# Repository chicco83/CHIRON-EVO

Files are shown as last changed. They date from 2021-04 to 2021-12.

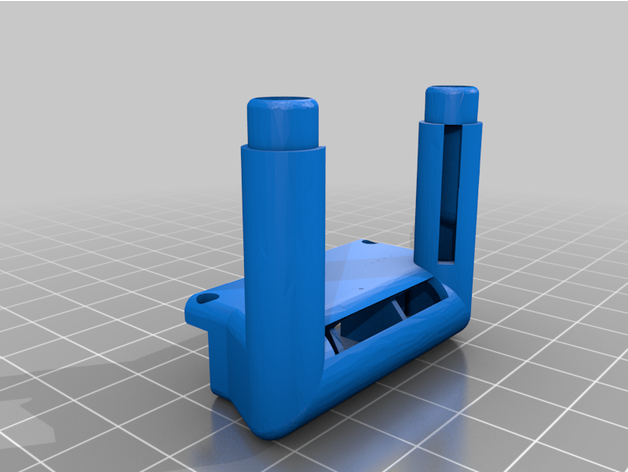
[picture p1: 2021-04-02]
CHIRON/MOD HARDWARE/Chiron+Fan+Duct+Shorter+for+better+print+clearance/images/CHIRON_FAN_DUCT_height_reduce.png

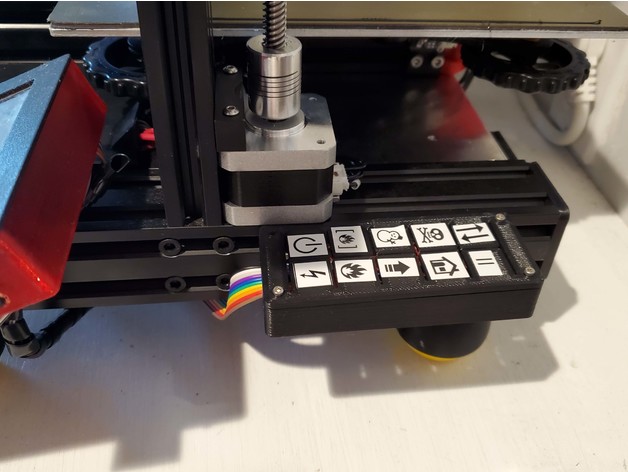
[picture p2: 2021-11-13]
CHIRON/MOD HARDWARE/PANNELLO PULSANTI/Octoprint+Buttonbox+/images/20200816_113341-2.jpg

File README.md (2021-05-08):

# CHIRON-EVO
repository delle modifiche che ho attuato alla mia anycubic chiron

UPDATES PRINTER.CFG

8-5-21 settato  stealthchop_threshold a 999 per assi X e Y e a 1 per Z, Z1 ed E quindi attivo sempre sui primi due assi e sempre disattivo su estrusore e asse Z
8-5-21 aggiunto SCREW ADJUST
8-5-21 aggiunto SuperSlicer_2.3.6a 4-5-21 NIGHTLY

FUNZIONI IMPLEMENTATE IN KLIPPER PRINTER.CFG

[output_pin power]
accensione e spegnimento della stampante tramite semplice rele che interrompe il positivo che esce dal connettore della spina. vedi foto nella sezione MOD HARDWARE / INSTALLAZIONE RELE

[idle_timeout]
se dopo 5 minuti dal riscaldamento la stampante non ha ricevuto input, ritrae il filamento spegne hotend e piatto, suona e da un output su console che avvisa dell'avvenuto idle_timeout

[temperature_sensor Raspberry CPU]  
nelle temperature viene mostrata anche quella della cpu del raspberry

gli stepper sono gia predisposti per lavorare con i driver 4988 o 2209
da calibrare in base alla propria meccanica le rotation_distance
https://github.com/KevinOConnor/klipper/blob/master/docs/Rotation_Distance.md

#[temperature_sensor TMC_2209]
aggiunto un semplice termistore da hotend collegato al pin t2 per monitorare la temperatura dei tmc al momento il codice è disattivato e gira quello nella sezione 

[temperature_fan stepper_driver_fan]
questo codice permette di settare la temperatura obiettivo da mantenere per i driver e la ventola varia in automatico la propria velocita.
per ottenere maggiore silezionsita ho collegato assieme alla ventola della scheda madre anche quella dell'alimentatore.

[endstop_phase]
assieme ai tmc 2209 permette una perfetta calibrazione degli endstop soprattutto sull'asse Z
https://github.com/KevinOConnor/klipper/blob/master/docs/Endstop_Phase.md

[verify_heater extruder]
attivo il controllo delle temperature analogo a marlin in modo da spegnere tutto se le letture delle temperature non sono congrue e quindi c'è un guasto

[verify_heater heater_bed]
come sopra per l'hot bed

[bed_mesh]
attiva la generazione della mesh tramite il sensore di livellamento. se non ne siete in possesso si puo comprare quello per la kossel su aliexpress oppure farlo da soli dato che  è un semplice switch come quello degli endstop meccanici

[pause_resume]
attivata la funzione di messa in pausa e ripresa della stampante

[firmware_retraction]
prevista la ritrazione da firmware ma lasciata disattivata a vantaggio della pressure advance

[gcode_arcs]
inserita la gestione degli archi

[input_shaper]
inserita la sezione per lo smorzamento delle vibrazioni. l'ideale è comprare l'accellerometro che costa pochi spiccioli e farla con quello
https://www.klipper3d.org/Resonance_Compensation.html

[output_pin BEEPER_pin]
abiltiato il beeper per creare macro con avvisi sonori

[filament_switch_sensor my_sensor]
supportato il sensore di fine filamento
in caso di fine filamento la stampante va in pausa ed emette un avviso sonoro.
al rilevamento del nuovo filo lo carica automaticamente:lentamente i primi 2 cm, velocemente i successivi 49 e di nuovo lentamente gli ultimi 6 cm
poi riprende la stampa

[SCREW TILT CALCULATE]
indica come regolare le viti del piatto per una perfetta messa in piano fisica

MACRO.CFG

[gcode_macro M600]
macro m600 per cambio filo

[gcode_macro POWER_OFF_PRINTER]
gcode:
  SET_PIN PIN=power value=0

[gcode_macro POWER_ON_PRINTER]
gcode:
  SET_PIN PIN=power value=1
accensione e spegnimento della stampante tramite rele

MOD HARDWARE PER LA STAMPANTE

hotend trianglelab e3d v6
https://it.aliexpress.com/item/32844313509.html?spm=a2g0s.9042311.0.0.27424c4dBxZaBv
una volta montato andranno alzati gli endstop ottici o stampate alette piu lunghe altrimenti non arriva a fare il trigger del fine corsa

estrusore trianglelab  bmg v2
https://it.aliexpress.com/item/32917029058.html?spm=a2g0s.9042311.0.0.27424c4dk6avcs

barre filettate di rinforzo M10 con pezzi stampati per sfruttare la totale altezza della stampante qui
il progetto non è mio e dalla struttura delle cartelle sembra derivare da thingverse su cui però non l'ho trovato quindi non so a chi dare i credit

driver tmc 2209 5 pz versione UART
https://it.aliexpress.com/item/33029587820.html?spm=a2g0s.9042311.0.0.27424c4dK0OpVI
SEGUE GUIDA DEDICATA

tastatore per autobed leveling
https://it.aliexpress.com/item/4000792963251.html?spm=a2g0s.9042311.0.0.27424c4dK0OpVI
io ho preso la stampante usata e non c'era
SEGUE GUIDA DEDICACATA

accellerometro per ottimizzazione delle vibrazioni
https://it.aliexpress.com/item/32922294688.html?spm=a2g0s.9042311.0.0.27424c4dk6avcs

aggiunta rele per spegnimento stampante da klipper.
va installato un rele sul filo rosso saldato al connettore della spina e spostato il jumper che imposta l'alimentazione della trigorilla nella posizione usb in modo che la scheda sia alimentata dal raspberry. vedi foto nella cartella MOD HARDWARE / INSTALLAZIONE RELE

ELEMENTI DA STAMPARE LEGATI A KLIPPER

ho creato una cartella dedicata sotto klipper. al momento contiene un case per il rasp e un supporto un tablet da 7 pollici da usare come interfaccia localae

SOFTWARE

win32imager per fare un clone di backup della sd
https://sourceforge.net/projects/win32diskimager/

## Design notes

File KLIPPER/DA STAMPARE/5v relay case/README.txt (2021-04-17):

Customizable 5V relay case (updated version) by Zerkin on Thingiverse: https://www.thingiverse.com/thing:3851101

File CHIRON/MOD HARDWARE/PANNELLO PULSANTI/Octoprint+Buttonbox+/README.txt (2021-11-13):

Octoprint Buttonbox  by eugland on Thingiverse: https://www.thingiverse.com/thing:4571839

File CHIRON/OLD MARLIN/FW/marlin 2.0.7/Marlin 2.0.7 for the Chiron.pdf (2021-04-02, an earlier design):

Marlin 2 for the Chiron by Nick Wells

1 | P a g e

# Marlin 2.0.7 for the Chiron

## Introduction

I do not work for Anycubic and have no affiliation with Anycubic Ltd.
I have created this custom version of Marlin to support the factory build of the Anycubic Chiron, as I am a Chiron owner and a long-term user of Marlin firmware.
You are installing this firmware because you want to try new features in Marlin and you know how to safely operate your machine.

This firmware has been tested on the standard factory build Chiron and the printer operates as expected. This is open source firmware that comes with no support, warranty or guarantees. You have chosen to install it and by doing so accept responsibility for any problems, failures and losses that may occur.
If you aren’t sure about upgrading firmware, then please don’t.

The upgrade process is very simple and you can return to the Anycubic standard firmware at any time using the file in this package, or by downloading it from the Anycubic website.

## Firmware Features

Here is a summary of the features enabled in the firmware

All Chiron hardware and front panel features are supported.

### Bed Levelling

- Mesh bed Levelling
- Sensor Bed Probing
- Manual level adjustment
- Enhanced single point adjustment
- Automatic mesh loading after homing

### Preset Calibration

- Stock Hotend PID tune profile
- Stock Heatbed PID tune profile
- Stock extruder E-Step Calibration

### Error Recovery

- Filament out detection and recovery enabled
- Power loss detection and recovery enabled (SD Printing only)
- Auto park head on Pause
- Validated temperature error detection (reduces spurious temperature warnings)

### Printing Features

- Marlin Linear Advance enabled (preset K=8.0)
- Marlin Junction Deviation (preset to 0.028)
- Live Z axis baby stepping movement from panel during print

### Folder Navigation

The SD card can be navigated like a normal PC folder.
Click a folder name to enter a folder and click .. to go back up to the previous folder.

## Which Version Chiron do I have?

There are newer factory builds of the Chiron with an updated TFT panel that works slightly differently.

## THIS FIRMWARE DOES NOT SUPPORT THE NEW TFT PANEL (yet!)

Original version supported ✓ | New version Not Supported ✗
Use Anycubic firmware v1.3.0 | Use Anycubic Firmware v1.3.5

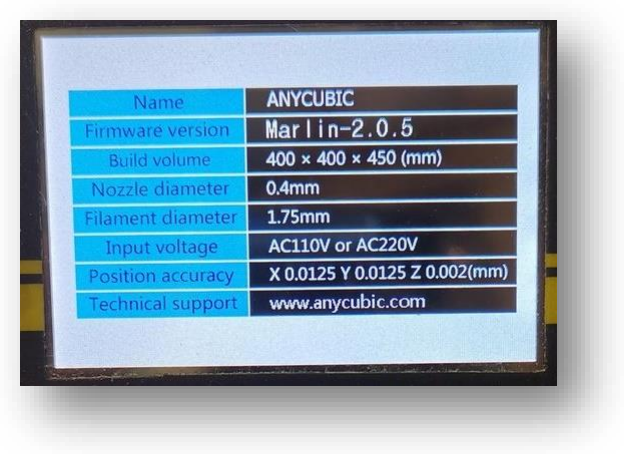
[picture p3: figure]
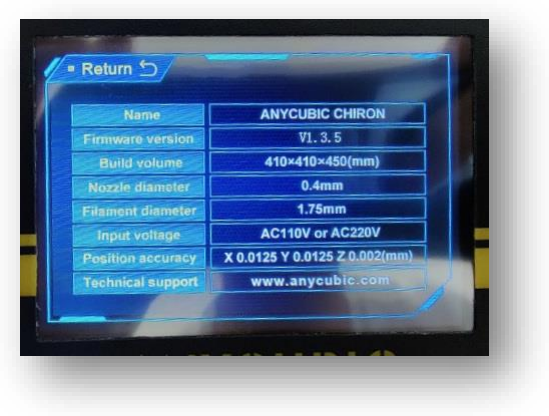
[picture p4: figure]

If you have installed the v2.07 by mistake you can reinstall the original Anycubic firmware in the pack.

## What’s in the package?

### The new Marlin Firmware

This is the version 2.0.7 release of Marlin customised for the Chiron and some command files to send to the printer. The printer will beep after running a command file.

File list

- CHIRON_2.0.7.hex
- Reset EEPROM.gcode
- PID Tune Hotend.gcode
- PID Tune Bed.gcode

### The standard Anycubic Firmware release

This is the standard Anycubic firmware. You can go back and install this version at any time by following the firmware quick start instructions on the next page.

For the old style TFT panel
File list
- CHIRON_1.3.0.hex
- Auto_Leveling.gcode
- Manual_Leveling.code

For the new style TFT panel
File list
- CHIRON_1.3.5.hex
- Auto_Leveling.gcode
- Manual_Leveling.code

There is also a copy of a free terminal program called Termite that may be useful!

## Firmware Installation Quick Start

Please follow these quick instructions to upgrade the printer and get printing. These instructions work with any version of firmware.

### Before You Start (Optional)

If you have already PID tuned and E-Step calibrated your printer it may be worth making a record of your settings. To do this connect a terminal program to the printer and send M503 to display settings. Save this info somewhere useful!

## Things you MUST DO or the printer won’t work correctly

### Upload the firmware

1) Connect your printer to a PC and launch Cura
2) In Cura got to Settings>Printer>Manage Printers…
3) Click Update Firmware then Upload Custom Firmware
4) Browse to the firmware file you want to install and click ok.
5) Once the firmware has installed the printer will reboot
6) You can check the version on the panel under Tools>More>Info

### Reset the printer settings

Every time you change a firmware version you must to reset the controller EEPROM.

Either send the commands M502 M500 from your PC

Or copy Reset EEPROM.gcode onto an SD card and print it.

### Level the bed

Follow the instructions on the next page to level the print bed.

### Things you SHOULD do for optimal printing

The settings in this firmware are specifically calibrated for the Chiron, but if you wish to re run the calibration here’s an easy way to do it!

PID tune the hotend
1) Copy the file PID Tune Hotend.gcode to the SD card and print it.
2) The printer will beep when finished.

PID tune the heated bed
1) Copy the file PID Tune Bed.gcode to the SD card and print it.
2) The printer will beep when finished.

Calibrate the extruder E-STEPS
Please read the included guide ‘Anycubic Chiron Step by Step Extruder flow calibration.pdf’

## How do things work?

### Bed Levelling

The bed levelling uses the Anycubic Probe which creates a 5 x 5 mesh that is used to adjust the Z axis position during print. The mesh is automatically saved after homing and is automatically loaded and applied every time the printer is homed.

Top Tip! The bed levelling will be more accurate if you probe the bed when it is hot!

### Here are the bed levelling steps: Please follow these steps carefully!

1) Home the printer
2) From the panel select Tools>More>Level>Probe make sure the probe is fitted then click OK. The printer will now probe the bed.
3) Once probing has finished, the head will park and you should remove the probe.
4) Now you must set the probe offset. Select Tools>More>Level>Advanced Setting
5) Tap red dot number 13 twice and the head will move to the centre of the bed and will be about 2mm above the bed.
6) Check the ‘ALL’ box and place a piece of paper under the head.
7) Use the +/- buttons to lower the head so that is grips the paper. You should be able to pull the paper but not push it. Now click OK.
8) The bed is now levelled!

### Mesh Point Adjustment

If you want to check and adjust individual points:
1) Home the printer
2) Go to the advanced level menu and click any of the red dots twice.
The head will move to the probe point and you can adjust the level using the +/- buttons on the panel.

NOTE: When using the Advanced Setting screen
- Click OK to save your changes
- Click back to cancel and revert to the last saved values.

### Filament Runout

When the filament runs out, the printer will beep and the head will park. The old filament will be ejected and the printer will beep then you load the new filament and the print will continue.
The extruder heater will shut down after 3 minutes, and will reheat before attempting to feed in the filament or restart the print. Use the ‘Continue’ button on the front panel to tell the printer to continue the process.

The filament workflow looks like this:
1) The filament runs out
2) The printer beeps and parks the head and shows a warning on the panel
3) Printer ejects the remaining filament then beeps 5 times and waits
4) Insert the new filament and click continue
5) The printer will slowly feed 50mm of filament
6) It will then accelerate and feed a further 500mm
7) Finally, it will slow down and purge the last 100mm
8) Once the filament starts to come out of the nozzle, click continue and the print will resume.

### Power loss Recovery

The printer can automatically recover a failed print during a power loss under the following conditions:

### 1. You must be printing from the SD card 2. The print file must be in the root folder 3. You must leave the front 10cm of the bed clear

Note: It is best to have just 1 or 2 files on the SD card for power loss recovery. If you have lots of files on the SD card, the power loss recovery may fail to save the last state when the power goes out. If this happens the job will not auto recover.

The power loss recovery works like this:
1) The power goes out!
2) The printer saves the current printer state into a file called PLR on the root of the SD card.
3) Manually move the print head off the print as it my get stuck.
4) Turn on the printer, you will hear an SOS beep to tell you the printer is in recovery mode.
5) Browse the SD card and select the file that was printing, then click ‘resume’.
6) The printer will home X and Y then will home Z so it should be clear of the print.
7) The bed and hotend will be reheated.
8) The head will then raise to a height 5mm above the point where the print failed.
9) The head will lower onto the print and it will resume where it left off.
10) The PLR file will be automatically deleted.

If the power fails again, the print will be recovered from the new fail point.

If you wish to cancel recovery mode:
1) resume the print then stop it
2) Print a different file
3) Delete the PLR file from the SD card.

### Live Baby Stepping during print

If you need to nudge the Z axis during a print you can now do this from the Advanced levelling menu.

Baby stepping works like this:
1) During a print Select Tools>More>Level>Advanced Setting
2) Make sure ALL is selected, the display will show 0.00
3) Each press of the +/- button will move the head by 0.05 mm
4) If you return to the menu during the print, that value will show how far the Z axis has been nudged.

At the end of the print the nudge value will be cleared. This is a temporary value that is not saved.

WARNING: This feature does not obey end stops so you can push the head into the bed with repeated movements, so use with caution!

### Source Code

The source code for this release is part of the main Marlin Github repository which you can find here:

https://github.com/MarlinFirmware/Marlin

The configuration files for the Chiron are located in the Marlin config repository here:

https://github.com/MarlinFirmware/Configurations

To build your own version of this firmware:

1) Download the Main Marlin Repository
2) Download the Marlin Configurations Repository
3) Replace configuration.h and configuration_adv.h in the Marlin\ folder with the versions in Configurations/config/examples/AnyCubic/Chiron/ in
the Configurations repository.
4) Build away!

### A quick shout out!

Thank you to:
Shane Dekart, Robert Filippo, Bob Modrow, Quentin McCain, Luca Marongiu, Marcin Nowak, JF Kerekes

For risking your machines testing the beta version of the firmware to help get it all working as it should!

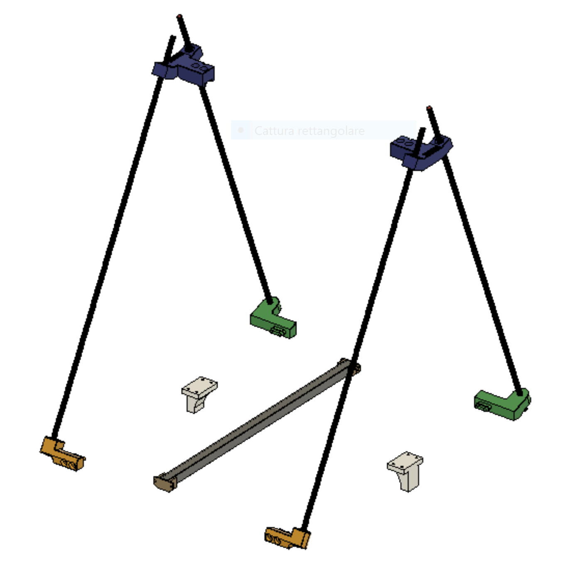
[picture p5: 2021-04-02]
CHIRON/MOD HARDWARE/Supporto Stabilizzante Chiron/Images/Anteprima Upgrade Chiron.PNG

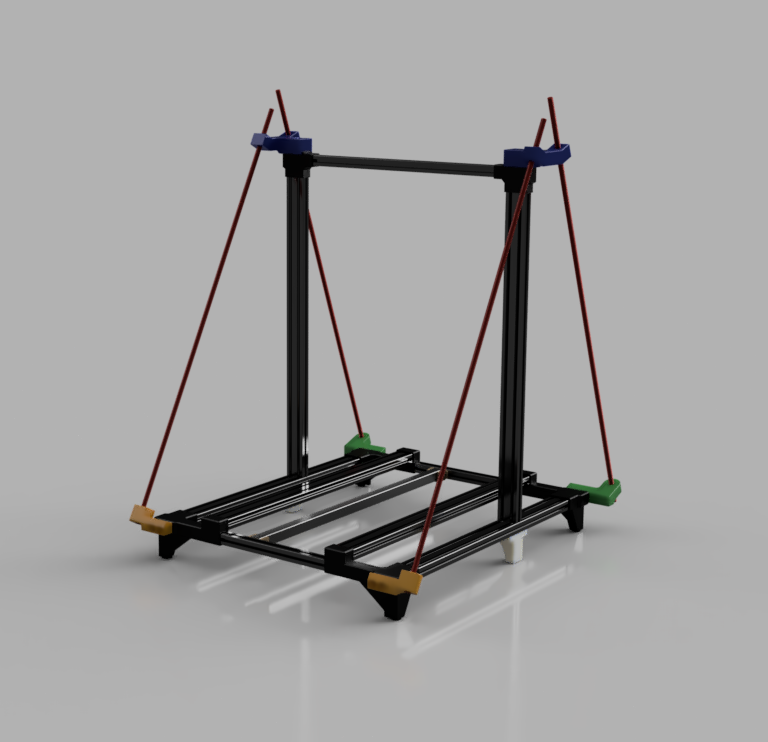
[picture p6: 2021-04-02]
CHIRON/MOD HARDWARE/Supporto Stabilizzante Chiron/Images/Rendering.PNG

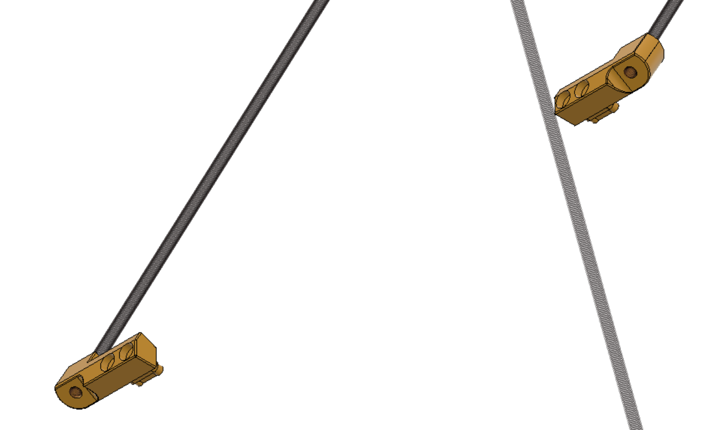
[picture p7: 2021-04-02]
CHIRON/MOD HARDWARE/Supporto Stabilizzante Chiron/Images/Supporto Anteriore Chiron.PNG

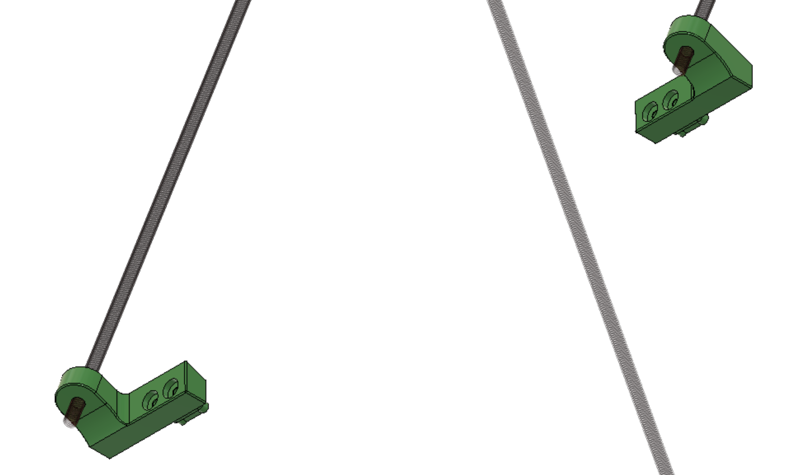
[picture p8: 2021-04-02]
CHIRON/MOD HARDWARE/Supporto Stabilizzante Chiron/Images/Supporto posteriore Chiron.PNG

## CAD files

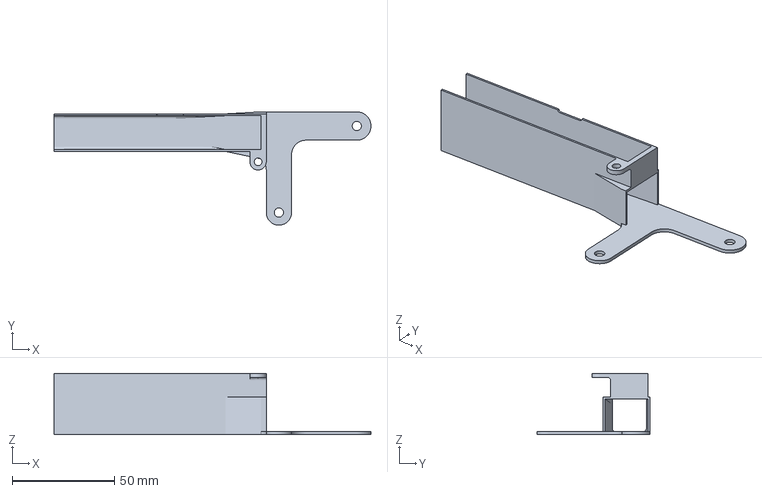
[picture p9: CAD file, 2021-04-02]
CHIRON/MOD HARDWARE/Anycubic_Trigorilla_stepper_driver_cooling_tunnel/files/Trigorilla_stepper_driver_cooling_duct_v2.3mf
154.7 x 55.3 x 30.0 mm

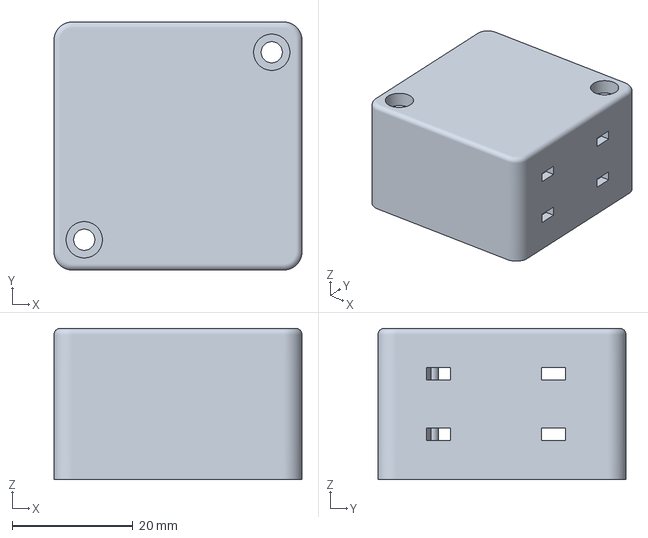
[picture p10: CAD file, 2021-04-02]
CHIRON/MOD HARDWARE/Chiron_X_stepper_cover_with_cable_guide/files/Fusion360_Chiron_cover.3mf
41.0 x 41.0 x 25.0 mm

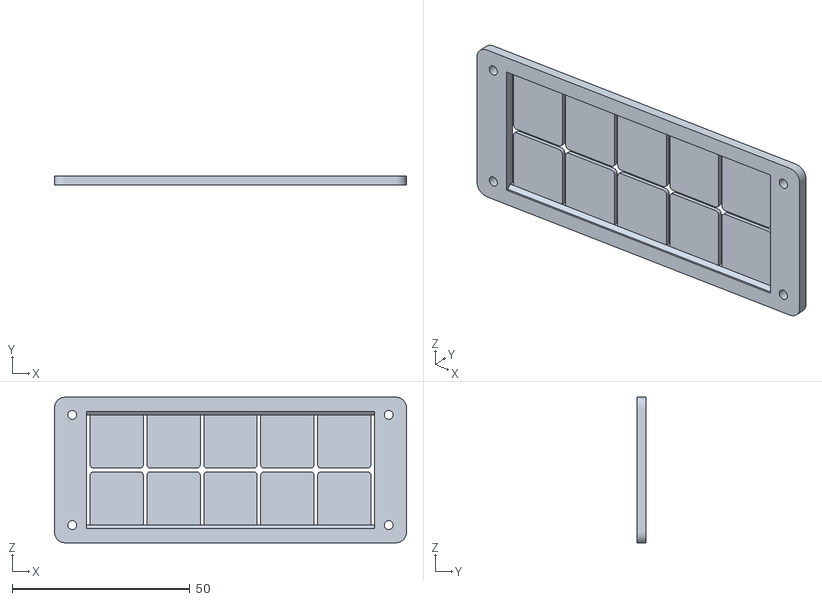
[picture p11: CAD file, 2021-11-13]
CHIRON/MOD HARDWARE/PANNELLO PULSANTI/Octoprint+Buttonbox+/files/buttonpad.stl
99.0 x 2.50 x 41.0

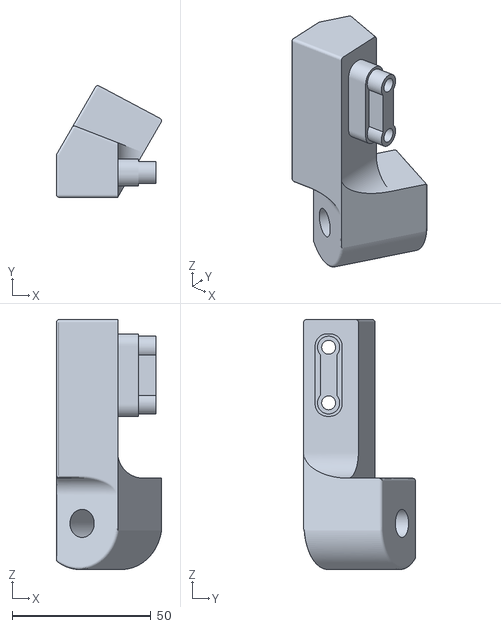
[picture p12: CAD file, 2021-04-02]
CHIRON/MOD HARDWARE/Supporto Stabilizzante Chiron/Files/fatti/Supporto anteriore barra M10 sx Chiron.stl
37.8 x 40.2 x 90.0

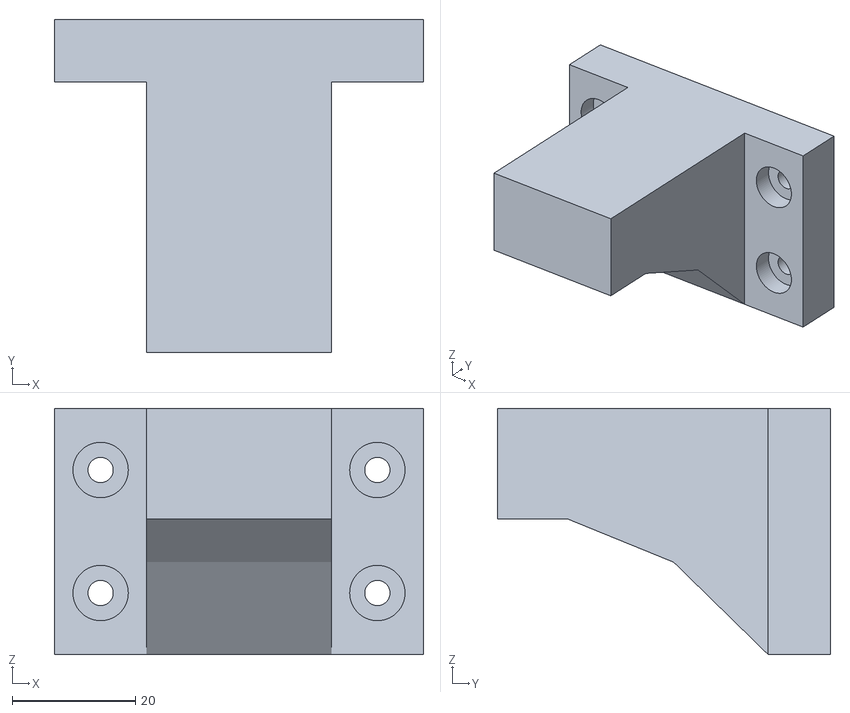
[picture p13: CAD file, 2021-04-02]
CHIRON/MOD HARDWARE/Supporto Stabilizzante Chiron/Files/Piede dx Z Chiron.stl
60.0 x 54.2 x 40.0

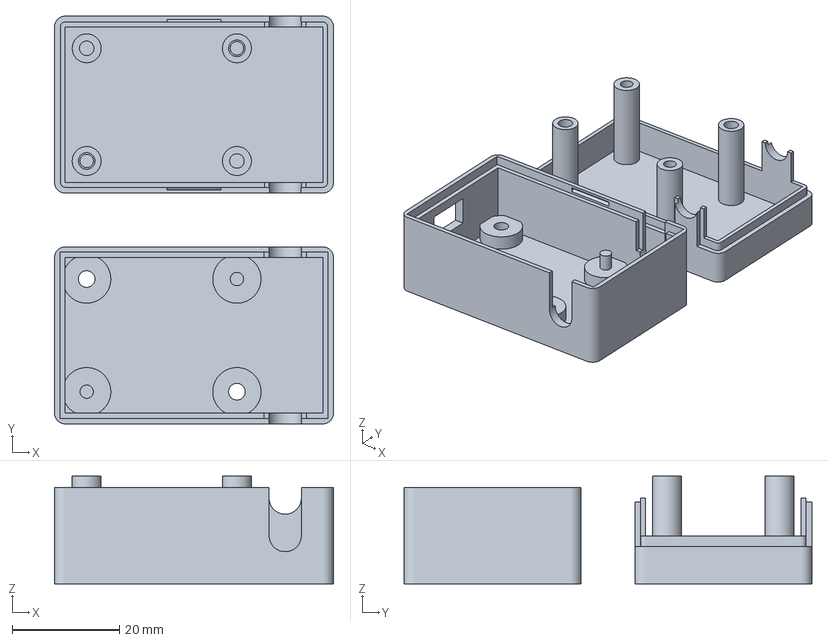
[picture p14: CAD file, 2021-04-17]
KLIPPER/DA STAMPARE/5v relay case/files/relay_case.3mf
52.0 x 76.0 x 20.1 mm

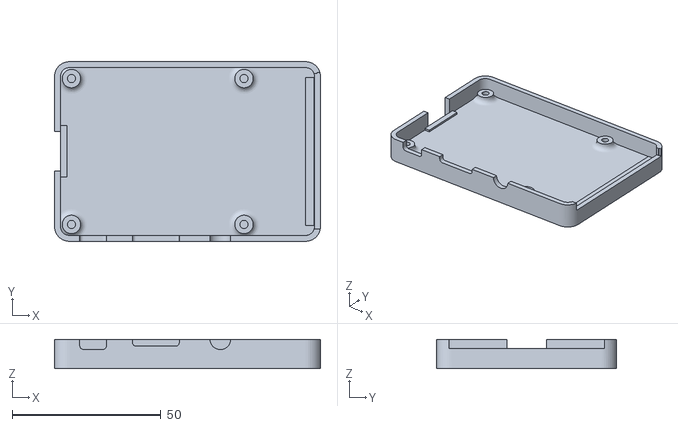
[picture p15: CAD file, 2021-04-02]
KLIPPER/DA STAMPARE/Raspberry_Pi_3_B_Case/files/Pi3_Bottom_Plain.stl
89.4 x 60.4 x 9.75

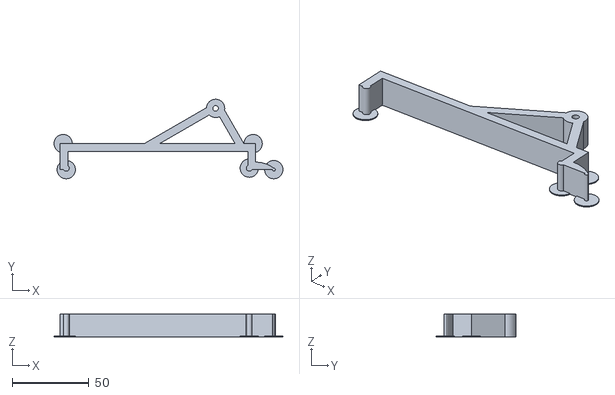
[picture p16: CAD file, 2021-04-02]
KLIPPER/DA STAMPARE/supporto tab 7/clip.stl
149.5 x 52.0 x 15.0

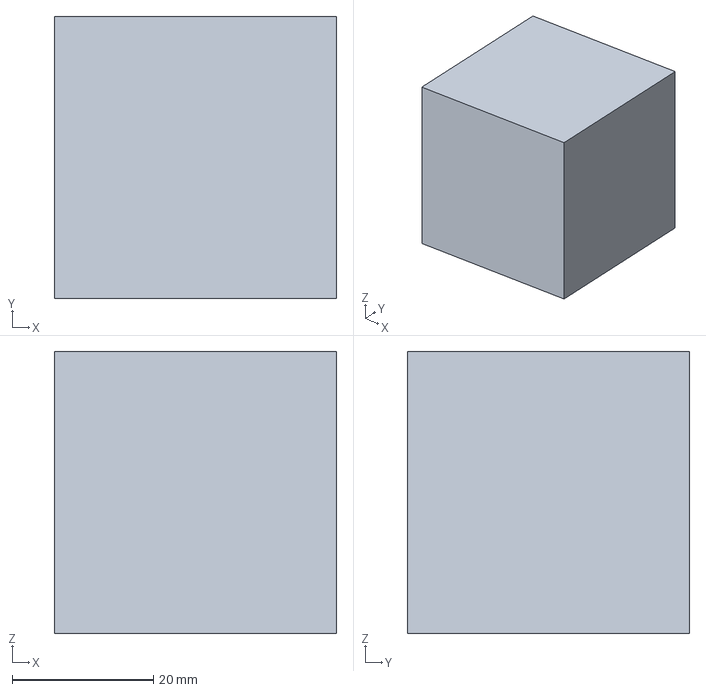
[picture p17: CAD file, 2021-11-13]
TARATURE/cubo flow test.3mf
40.0 x 40.0 x 40.0 mm

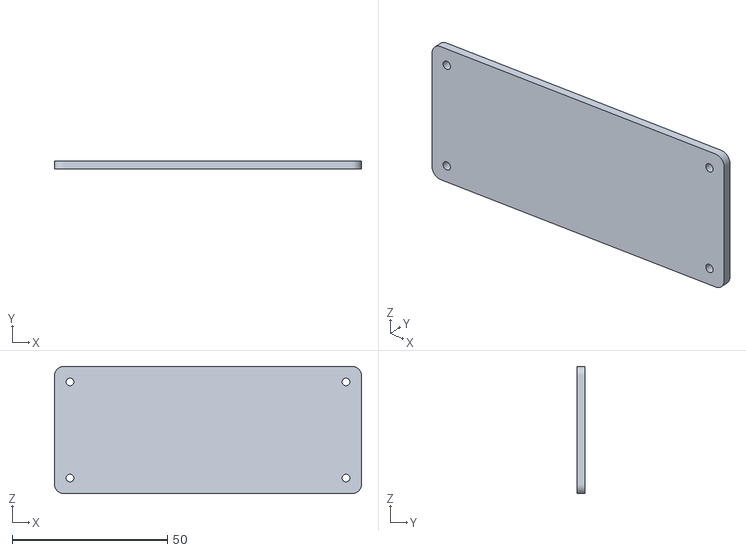
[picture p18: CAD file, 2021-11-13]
CHIRON/MOD HARDWARE/PANNELLO PULSANTI/Octoprint+Buttonbox+/files/tappo inferiore.stl
99.0 x 2.50 x 41.0

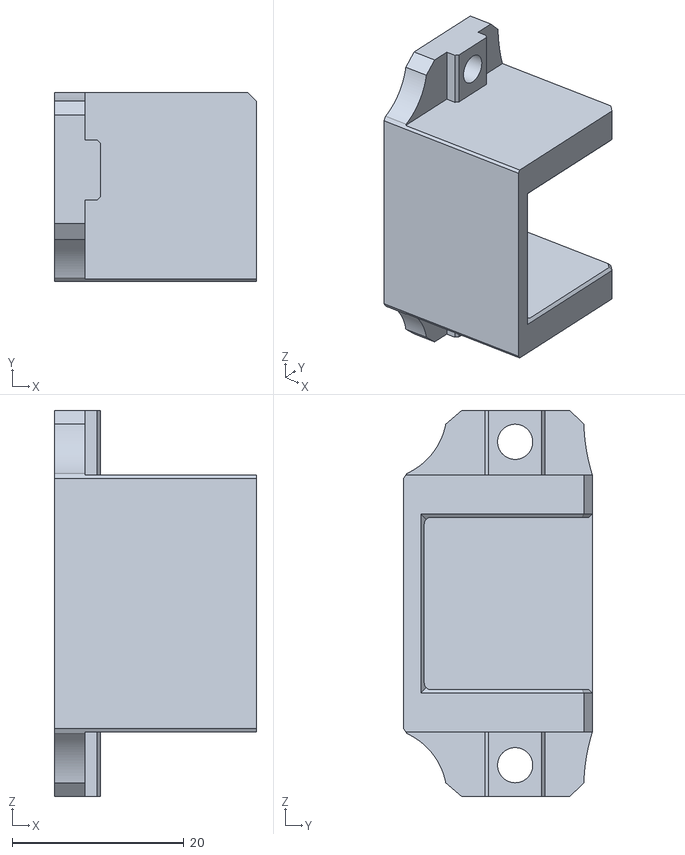
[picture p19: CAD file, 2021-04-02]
CHIRON/MOD HARDWARE/Supporto Stabilizzante Chiron/Files/fatti/Rinforzo asse y scatolato 2020 anteriore Chiron.stl
23.6 x 22.0 x 45.0

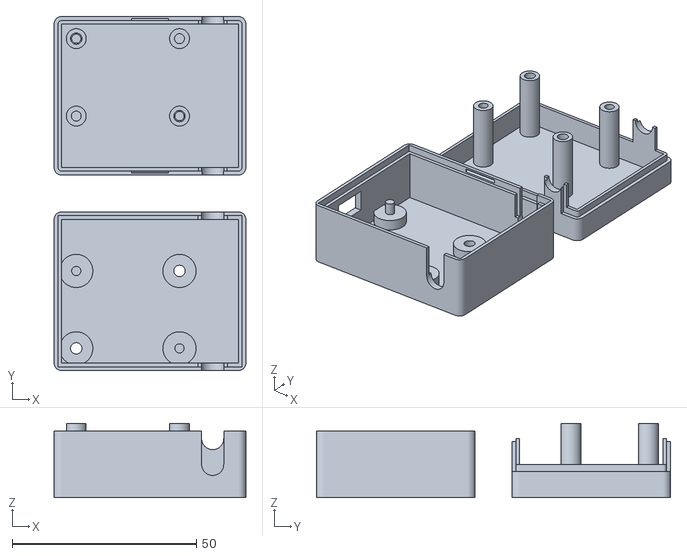
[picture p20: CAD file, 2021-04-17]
KLIPPER/DA STAMPARE/5v relay case/files/relay_case_wide.stl
52.0 x 96.0 x 20.1

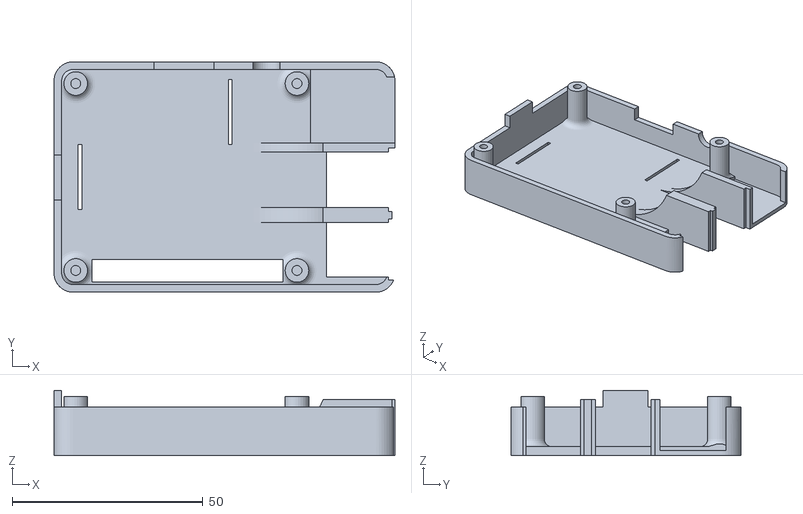
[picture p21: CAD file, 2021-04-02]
KLIPPER/DA STAMPARE/Raspberry_Pi_3_B_Case/files/Pi3_Top_GPIO.stl
89.4 x 60.4 x 17.1

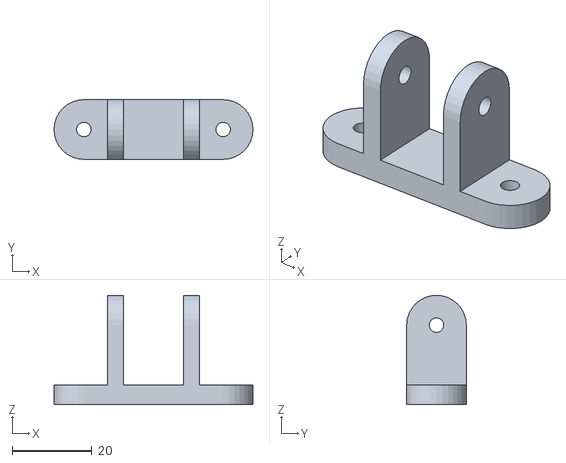
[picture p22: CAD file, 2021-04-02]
KLIPPER/DA STAMPARE/supporto tab 7/mount.stl
50.0 x 15.0 x 27.5

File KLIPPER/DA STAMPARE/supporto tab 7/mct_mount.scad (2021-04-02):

// This script creates a mount for the MatterControl Touch
// tablet for attaching to a 3D printer. 
// 
// I wanted to create this mount so that I can mount my
// MatterControl Touch to the printer in place of the LCD panel.
// If you haven't used one of these before, you will be 
// amazed at its power, ease of use, and convenience. Simply
// stated, the MatterControl Touch is the LCD panel you've 
// always wanted but have never found. There have been some 
// other good attempts at a full featured LCD/computer mount
// but this one is the best hands down. Don't take my word(s)
// for it - try one yourself.
//
// As you can see, you can modify this script to change the
// mount if you want a different type - clamp or whatever.
// You can also change the length of the arm if you want the 
// table to be further away from the print bed. Feel free
// to customize at will!
// 
// Vitamins:
//
// (2) M3 nylock nuts
// (2) M3 nuts
// (2) 15x30mm strips of self adhesive foam ~1/8" thick
// (4) M3 washers
// (1) M3x25mm bolt
// (1) M3x50mm bolt
// (2) M3x8mm bolts
// (1) MatterControl Touch ;)
//
// Note: you may be able to substitute #6 bolts for the longer M3,
//       but you may need to drill out the holes a bit. Or, better,
//       modify the code to use larger holes.
// 
// Instructions:
//
// 1. Print (1) arm, (1) mount, and (2) clips. PLA is fine.
//    I would use 0.3 layer height and 40% infill for strength.
//    No supports are needed. There are pads on the clip at key locations 
//    to help prevent lifting. Just cut those away when printed.
// 2. Attach the mount to the printer using (2) M3x8 bolts and (2) M3 nuts.
// 3. Attach the arm to the mount using (1) M3x25 bolt, (2) M3 washers and 
//    (1) M3 nylock. Do not tighten, just snug the bolt.
// 4. Attach the clips to either side of the arm using (1) M3x50 bolt,
//    (2) M3 washers, and (1) M3 nylock. Do not tighten, just snug the bolt.
// 5. Attach foam strips.
// 6. Clip the MatterControl Touch into the clip, position, and tighten
//    the bolts. 
//    Tip: Use the camera preview to sight your build plate.
// 
// Created by: drcharlesbell@gmail.com
//
// Enjoy!

module clip(height=3) {
    difference() {
        union() {
            cube([127.5,17,height]);
            // lever
            translate([127.5,-15,0]) cylinder(height,r=20,$fn=32);
            // mount
            translate([51.5,15,0]) rotate([0,0,-60]) cube([5,55,height]);
            translate([116.5,13,0]) rotate([0,0,30]) cube([5,30,height]);
            translate([101.5,40,0]) cylinder(height,r=6,$fn=32);
        }
        translate([5,0,0]) cube([117.5,12,height]);
        translate([100,-40,0]) cube([50,40,height]);
        // mount hole
        translate([101.5,40,-1]) cylinder(height+2,r=1.82,$fn=32);
    }
    // snap clips
    translate([4,1,0]) cylinder(height,r=2,$fn=32);
    translate([123.5,1,0]) cylinder(height,r=2,$fn=32);
    // lever
    translate([139.5,0,0]) cylinder(height,r=1,$fn=32);
    // pads for lift control
    translate([4,0,0]) cylinder(0.5,r=6,$fn=32);
    translate([2,17,0]) cylinder(0.5,r=6,$fn=32);
    translate([126,17,0]) cylinder(0.5,r=6,$fn=32);
    translate([123.5,1,0]) cylinder(0.5,r=6,$fn=32);
    translate([139.5,0,0]) cylinder(0.5,r=6,$fn=32);
}

module mount() {
    difference() {
        union() {
            cube([35,15,5]);
            translate([6,0,5]) cube([23,15,15]);
            translate([6,7.5,20]) rotate([0,90,0]) cylinder(23,r=7.5,$fn=32);
            translate([0,7.5,0]) cylinder(5,r=7.5,$fn=32);
            translate([35,7.5,0]) cylinder(5,r=7.5,$fn=32);
        }
        translate([10,0,5]) cube([15,15,30]);
        translate([0,7.5,0]) cylinder(5,r=1.82,$fn=32);
        translate([35,7.5,0]) cylinder(5,r=1.82,$fn=32);
        translate([5,7.5,20]) rotate([0,90,0]) cylinder(25,r=1.82,$fn=32);
    }
}

module arm(length=30,height=3) {
    difference() {
        union() {
            cube([length,height,height]);
            translate([0,height/2,0]) cylinder(height,r=height/2,$fn=32);
            translate([length,7.5,0]) cylinder(height,r=height/2,$fn=32);
        }
        translate([0,height/2,-1]) cylinder(height+2,r=1.82,$fn=32);
        translate([length,height/2,-1]) cylinder(height+2,r=1.82,$fn=32);
    }
}

translate([0,-25,0]) mount();
clip(15);
translate([0,-45,0]) arm(40,15);

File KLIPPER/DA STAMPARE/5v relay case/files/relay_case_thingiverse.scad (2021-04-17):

// 5V relay case
// GNU GPL v3
// version : 2.1
// Author : Zerkin
// date : 14/11/2020

// applied correction from goodone for top column height

// --------------
/*[General parameters]*/
// the number of facets used to generate an arc
$fn = 64 ;

// Tolerance for assembling part in mm
Margin=0.1 ;

// --------------
// Adjustable variables

/*[Box size]*/
// inner length (X axis) in mm
Length=48 ;
// inner width (Y axis) in mm
Width=29 ;
// inner base height (Z axis) in mm
Base_height=16 ;
// Inner top height in mm
Top_height=5 ;

// Wall thickness in mm
Thickness=2 ;


/*[Supports]*/
// alignment mode : centered | align on right side | align on left side
Align = 1 ; // [0:center, 1:right, 2:left]
// Space between the center of first support and the front side
Space_x = 4 ;
// Space between the center of support and the side (for left ot right alignment)
Space_y = 4 ;

//
// Distance between holes in X axis
Support_x=28;
// Distance between holes in Y axis
Support_y=21;
// Height of the support
Support_z=3 ;

// Type of support : 0=simple, 1=with column, 2=M3x6 Bolt from above in hexagonal nut, 3=M3 Bolt from bottom in column
Support_type = [1, 3, 1, 3] ;

// diameter of the support plot (need to be wide enough if using nut)
Support_r = 4.5 ;
// diameter of the column above the plot
Column_r = 2.7 ;
// length of the Bolt (for type 3 support)
Bolt_length = 12 ;


/*[Pin Hole]*/
// Y center position (from center of board)
Pin_y=-2.5;
// Z lower position (from bottom of board)
Pin_z=3;

// Y size
Pin_size_y=10;
// Z size
Pin_size_z=6; 

// Text centered below the hole
Text="S  +  -"; 
// Text size
Text_size = 3;   


/*[Power Cord hole]*/
// X position for the center of the power cord hole (from outside)
Hole_x=43;
// Z position for the center of the power cord hole
Hole_z=9;
//Diameter in mm (-1 to remove completly)
Hole_r=3;


/* [Hidden] */
// M3 Bolt parameters
Bolt_hole_d = 2.5 ;
Bolt_passage_d = 3.1 ;
Bolt_head_h = 2.1 ; // 2 + 0.1 mm
Bolt_head_d = 6.4 ; // 5.4 + 1 mm
Nut_h = 2.5 ; // 2.3 + 0.2 mm
Nut_d = 6.6 ; // 6.4 + 0.2 mm
Screwing_length = 6 ;

// Pcb size
Pcb_height = 1.7 ;

// Translation for the center of the support
Y_translation = ( Align==0 ? Width/2 : (Align==1 ? Space_y+Support_y/2 : Width - (Space_y+ Support_y/2) ) ) ;

// --------------
// modules definition

// Cube with rounded vertical ridge
module roundedCube(size, radius) {
    hull() {
        translate([radius, radius]) cylinder(r = radius, h = size[2]);
        translate([size[0] - radius, radius]) cylinder(r = radius, h = size[2]);
        translate([size[0] - radius, size[1] - radius]) cylinder(r = radius, h = size[2]);
        translate([radius, size[1] - radius]) cylinder(r = radius, h = size[2]);
    }
}

// triangular prism for holding the top part
module prism(e,w){
   translate([-w/2, 0, -e]) polyhedron(
       points=[[0,0,0], [w,0,0], [w,e,e], [0,e,e], [0,0,2*e], [w,0,2*e]],
       faces=[[0,1,2,3],[5,4,3,2],[0,4,5,1],[0,3,4],[5,2,1]]
   ) ;
}


module plot(type)
{
   translate([0,0,Thickness - Margin]) {
      cylinder(r=Support_r, h=Support_z + Margin);
      cylinder(d=Bolt_hole_d, h=Support_z + 2*Pcb_height + Margin);
   }
}

module plot_hole(type)
{
   if (type==2) {
      translate([0,0,-Margin]) cylinder (h=Nut_h+Margin, d=Nut_d, $fn=6 ) ;
      cylinder (h=Thickness+Support_z+2*Pcb_height+3*Margin, d=Bolt_passage_d );
   }
   if (type==3) {
      translate([0,0,-Margin]) cylinder (h=Thickness+Support_z+2*Pcb_height+3*Margin, d=Bolt_passage_d );
      translate([0,0,-Margin]) cylinder(h=Bolt_head_h + Margin, d = Bolt_head_d) ;
   }
}

module plot_top(type)
{
   Column_height = Base_height + Top_height + Thickness - (Support_z + Pcb_height + 2*Margin) ;
   Column_Bolt_hole_height = Bolt_length + Bolt_head_h - (Support_z + Pcb_height + Margin) ;
   Screw_length = min(Screwing_length, Column_Bolt_hole_height) ;
   
   hole_length = (type==1 ? Pcb_height + 2*Margin : Column_Bolt_hole_height+Margin) ;
   diameter = (type==1 ? Bolt_hole_d+2*Margin : Bolt_hole_d) ;
 
   if (type==1 || type==3)
      difference () {
         cylinder(h=Column_height, r=Column_r) ;

         translate ([0,0,Column_height-hole_length-2*Margin]) cylinder (h=hole_length + 3*Margin, d=diameter) ;
         if (type==3) 
            translate ([0,0,Column_height-hole_length+Screwing_length]) cylinder (h=hole_length + 3*Margin, d=Bolt_passage_d) ;
      }
}


// --------------
// Objects definition


module base(){
    difference () {
        // Base unit
        roundedCube( [Length+2*Thickness, Width+2*Thickness, Base_height+Thickness], Thickness) ;

        // hollowing the box
        translate([Thickness,Thickness,Thickness]) cube ([Length, Width, Base_height+Thickness], false);
        translate([Thickness/2, Thickness/2, Base_height]) cube ([Length + Thickness, Width + Thickness, 2*Thickness]);
        
        
        // Recess for lid
        translate([Thickness+(Length/2), 1.5*Thickness + Width - 0.1, Base_height + Thickness/2]) prism(Thickness/4+0.1, 10) ;
        translate([Thickness+(Length/2), 0.5*Thickness + 0.1, Base_height + Thickness/2]) rotate([0,0,180]) prism(Thickness/4+0.1, 10) ;
        

        // Pin opening
        translate([-Thickness, Thickness + Y_translation + Pin_y - Pin_size_y/2, Thickness + Support_z + Pin_z]) cube([3*Thickness, Pin_size_y, Pin_size_z], false) ;
        translate([1-Margin, Thickness + Y_translation + Pin_y , Thickness + Support_z + Pin_z - Text_size - 1 ]) rotate([90,0,-90]) linear_extrude(height = 1+Margin)
            text(Text, size=Text_size, font="Arial:style=bold", halign="center");
        
       
        // Outside opening for power cord
        translate([Hole_x, -Thickness, Hole_z]) {
            rotate([-90, 0,0]) cylinder(r = Hole_r, h = Width+4*Thickness);
        }
        translate([Hole_x-Hole_r, -Thickness, Hole_z]) cube([2*Hole_r, Width+4*Thickness, Base_height-Hole_z+2*Thickness ], false) ;

        // Inside shape for power cord 
        translate([Hole_x-Hole_r-Thickness/2, Thickness/2, Hole_z]) cube([2*Hole_r+Thickness, Width+Thickness, Base_height-Hole_z+2*Thickness ], false) ;
    }
    
    // Supports
    translate([Thickness + Space_x, Thickness + Y_translation]) union () {
      translate([0, -Support_y/2])           plot(Support_type[0]);
      translate([0,  Support_y/2])           plot(Support_type[1]);
      translate([Support_x,  Support_y/2])   plot(Support_type[2]);
      translate([Support_x, -Support_y/2])   plot(Support_type[3]);
    }

}

translate([0, 0, 0]) difference()
{
   base() ;

   translate([Thickness + Space_x, Thickness + Y_translation, -Margin]) union () {
      translate([0, -Support_y/2])           plot_hole(Support_type[0]);
      translate([0,  Support_y/2])           plot_hole(Support_type[1]);
      translate([Support_x,  Support_y/2])   plot_hole(Support_type[2]);
      translate([Support_x, -Support_y/2])   plot_hole(Support_type[3]);
   }
}

// lid
translate([0, Width+2*Thickness + 10, 0]) {
   difference(){
      union() {
         // Base unit
         roundedCube( [Length+2*Thickness, Width+2*Thickness, Top_height+Thickness], Thickness) ;
         // inside wall
         translate([Thickness/2+Margin, Thickness/2+Margin, Top_height+Thickness]) roundedCube( [Length+Thickness-2*Margin, Width+Thickness-2*Margin, Thickness-Margin], Thickness/2-Margin) ;


         // closing recess
         translate([Thickness+(Length/2), 1.5*Thickness + Width - Margin, Top_height+ 1.5*Thickness]) prism(Thickness/4, 10) ;
         translate([Thickness+(Length/2), Thickness/2 + Margin, Top_height+ 1.5*Thickness]) rotate([0,0,180]) prism(Thickness/4, 10) ;


         // Wall for closing power cord hole
         // extern wall
         translate([Hole_x-Hole_r+Margin, 0, Top_height+Thickness]) cube([2*(Hole_r-Margin), Width+2*Thickness, Base_height-Hole_z+Thickness ], false) ;
         // inside wall (bigger) 
         translate([Hole_x-Hole_r-Thickness/2+Margin, Thickness/2+Margin, Top_height+Thickness]) cube([2*(Hole_r-Margin)+Thickness, Width+Thickness-2*Margin, Base_height-Hole_z+Thickness ], false) ;

      }

      // hollowing the lid
      translate([Thickness,Thickness,Thickness]) cube ([Length, Width, Top_height+Base_height], false);

      // Hole for power Cord
      translate([Hole_x, -Thickness, Top_height+Base_height-Hole_z+2*Thickness ]) 
         rotate([-90, 0,0]) cylinder(r = Hole_r, h = Width+4*Thickness);
   } ;
   
   
   // Column above the support plots
   translate([Thickness + Space_x, Thickness + Width - Y_translation]) union () {
      translate([0,  Support_y/2])           plot_top(Support_type[0]);
      translate([0, -Support_y/2])           plot_top(Support_type[1]);
      translate([Support_x, -Support_y/2])   plot_top(Support_type[2]);
      translate([Support_x,  Support_y/2])   plot_top(Support_type[3]);
   }
}

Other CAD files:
TARATURE/Calibration cube.3mf
CHIRON/MOD HARDWARE/PANNELLO PULSANTI/Octoprint+Buttonbox+/files/button_base_v2.stl
CHIRON/MOD HARDWARE/Supporto Stabilizzante Chiron/Files/fatti/Piede dx Z Chiron.3mf
KLIPPER/DA STAMPARE/Raspberry_Pi_3_B_Case/files/Pi3_Top_Honeycomb.3mf
CHIRON/MOD HARDWARE/Anycubic_Trigorilla_stepper_driver_cooling_tunnel/files/Trigorilla_stepper_driver_cooling_duct_v2.stl
CHIRON/MOD HARDWARE/Chiron_X_stepper_cover_with_cable_guide/files/Fusion360_Chiron_cover.stl
CHIRON/MOD HARDWARE/PANNELLO PULSANTI/Octoprint+Buttonbox+/files/BUTTONS.3mf
CHIRON/MOD HARDWARE/PANNELLO PULSANTI/Octoprint+Buttonbox+/files/BUTTONS.stl
CHIRON/MOD HARDWARE/PANNELLO PULSANTI/Octoprint+Buttonbox+/files/Component3.ipt
CHIRON/MOD HARDWARE/PANNELLO PULSANTI/Octoprint+Buttonbox+/files/base.iam
CHIRON/MOD HARDWARE/PANNELLO PULSANTI/Octoprint+Buttonbox+/files/button_box_.iam
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

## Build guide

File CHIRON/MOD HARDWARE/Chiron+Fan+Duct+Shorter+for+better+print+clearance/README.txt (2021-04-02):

Chiron Fan Duct Shorter for better print clearance by JeenyusPete on Thingiverse: https://www.thingiverse.com/thing:4689052

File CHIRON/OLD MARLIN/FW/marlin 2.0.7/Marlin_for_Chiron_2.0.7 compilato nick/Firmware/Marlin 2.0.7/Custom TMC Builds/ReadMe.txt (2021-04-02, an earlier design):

The Builds in this folder have different options set for use 
if you have replaced the stepper drivers in your printer.

PLEASE NOTE: These builds are are based on the same code and the main firmware                      release, but the actual configurations have not been tested.

Chiron_2.0.7_TMC2208_Standalone.hex
  All stepper drivers set to TMC2208_STANDALONE

Chiron_2.0.7_TMC2208_Standalone_Reversed.hex
  All stepper drivers set to TMC2208_STANDALONE
  Stepper directions are all inverted.

Chiron_2.0.7_TMC2209_Standalone.hex
  All stepper drivers set to TMC2209_STANDALONE

Chiron_2.0.7_TMC2209_Standalone_Reversed.hex
  All stepper drivers set to TMC2209_STANDALONE
  Stepper directions are all inverted.

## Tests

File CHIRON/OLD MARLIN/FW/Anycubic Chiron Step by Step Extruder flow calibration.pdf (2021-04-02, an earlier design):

Nick’s Noobs guide to extruder calibration

1 | P a g e

# Extruder flow calibration

This is a simple guide that takes you through why and how you should calibrate your extruder flow.

## What is flow calibration?

The extruder is driven by a stepper motor, that must rotate certain number of steps for every millimetre of filament pushed through the hot end. This is defined in the printer controller as steps/mm.

## Why do this?

If the extruder is feeding too much filament (over extruding), you can get blobs (extruder bogies) being dropped into the print.

If the extruder is feeding too little filament (under extruding), you can get gaps or strings in the print as the extruded filament is stretched too much.

## What do I need to do this?

- A pencil (to mark the filament)
- A ruler or calliper (to measure the moved filament)
- A Computer and Terminal program (to send commands to the printer)

## How do I do this?

Before the full step by step guide, I want to explain what you will be doing.

Your printer uses a language called GCODE (http://marlinfw.org/meta/gcode/) to print, which is created by the slicer tool you use. There are lots of GCODE commands to set up and configure the printer too and you will be sending these commands one at a time using a simple terminal program. (Termite (https://www.compuphase.com/software_termite.htm) is a good free example)

To calibrate the flow, you will need to do the following:

1) Connect your printer to a PC and send a command using the terminal program
2) Read the current steps/mm setting from the printer using the terminal program
3) Make a mark on the filament near the extruder
4) Send commands to the printer to heat up the extruder, then feed 20mm of filament
5) Measure the amount of filament actually extruded
6) Calculate the difference between the 20mm you asked for and what was actually fed.
7) Calculate the new steps/mm number using the answer above
8) Set the new steps/mm on your printer using the terminal program
9) Save the settings so your printer remembers the new calibration when you turn it off.
10) Congratulations! Your feed rate is now calibrated!!

## Calibrating the Anycubic Chiron Extruder

NOTE:
Make sure Cura or any other print slicing tool is closed, or you won’t be able to send commands to your printer.

### Step 1 Talk to the printer

Turn on the printer and connect the USB cable to your PC.

Open the Termite program and click the settings | Select the Port for your printer (probably 5 or 6)
Button. | set the Baud rate to 250000 then click OK.

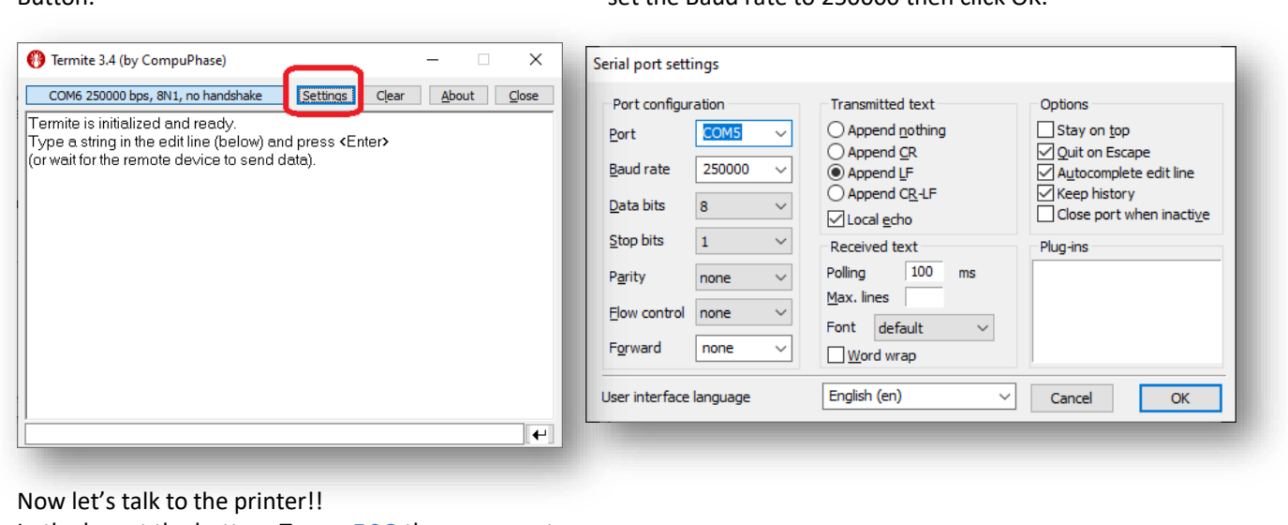
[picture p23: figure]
Now let’s talk to the printer!!

In the box at the bottom Type M503 then press enter.

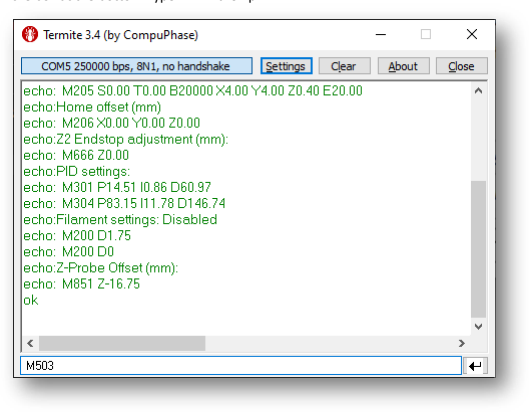
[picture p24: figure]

You have just asked the printer to report all settings, which hopefully it has! If nothing happens, set a different COM port number and try again.

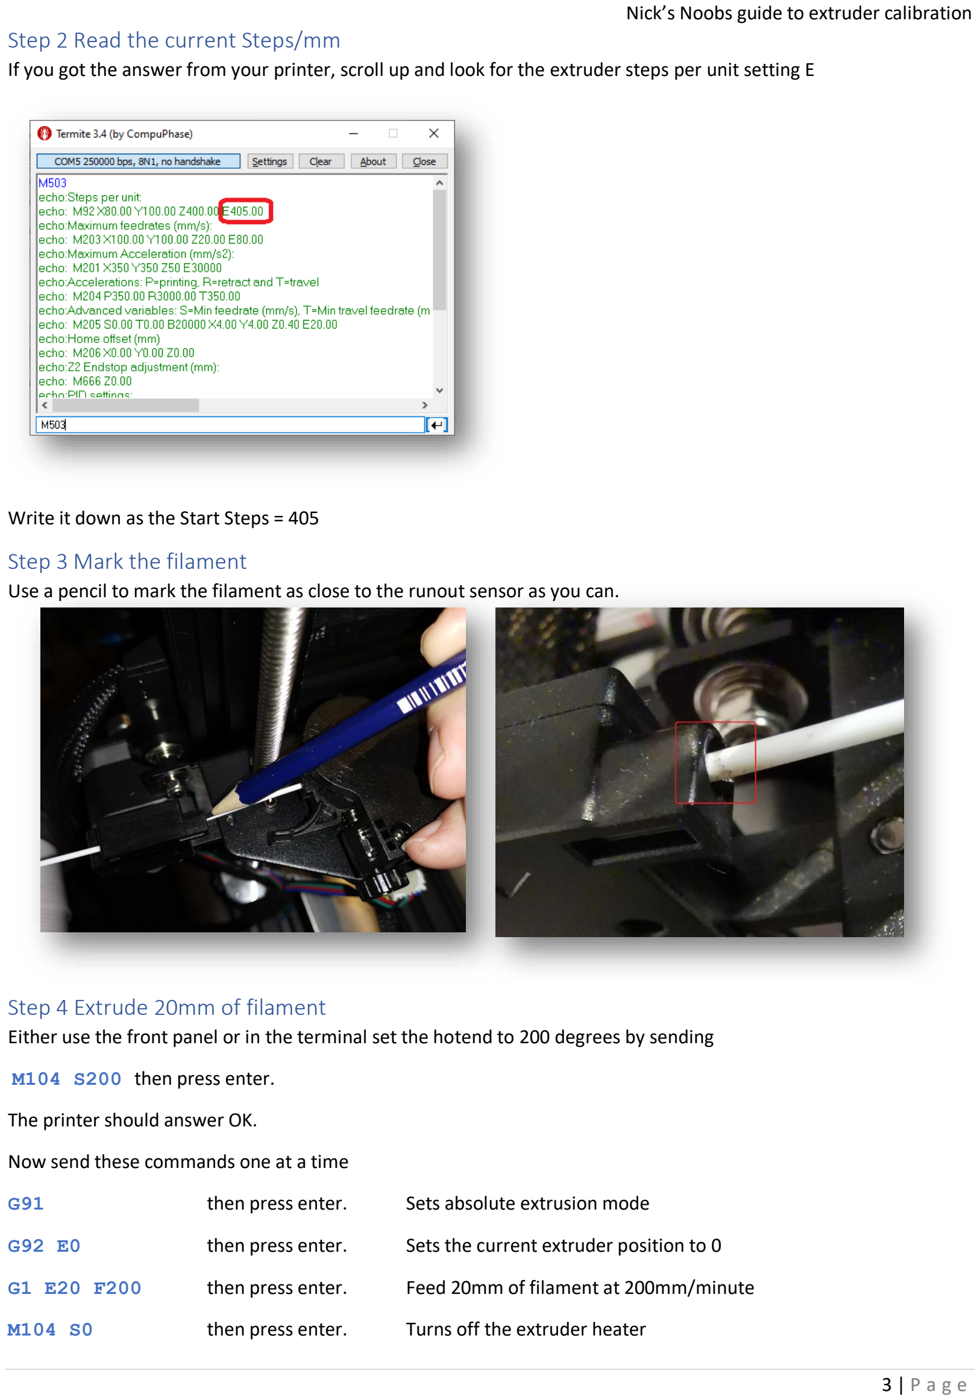
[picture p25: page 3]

### Step 2 Read the current Steps/mm

If you got the answer from your printer, scroll up and look for the extruder steps per unit setting E

Write it down as the Start Steps = 405

### Step 3 Mark the filament

Use a pencil to mark the filament as close to the runout sensor as you can.

### Step 4 Extrude 20mm of filament

Either use the front panel or in the terminal set the hotend to 200 degrees by sending

M104 S200 then press enter.

The printer should answer OK.

Now send these commands one at a time

G91 | then press enter. | Sets absolute extrusion mode
G92 E0 | then press enter. | Sets the current extruder position to 0
G1 E20 F200 | then press enter. | Feed 20mm of filament at 200mm/minute
M104 S0 | then press enter. | Turns off the extruder heater

### Step 5 Measure the extruded filament

Use a ruler and measure the distance between the pencil mark and the run out sensor. If the calibration is correct it should be exactly 20mm

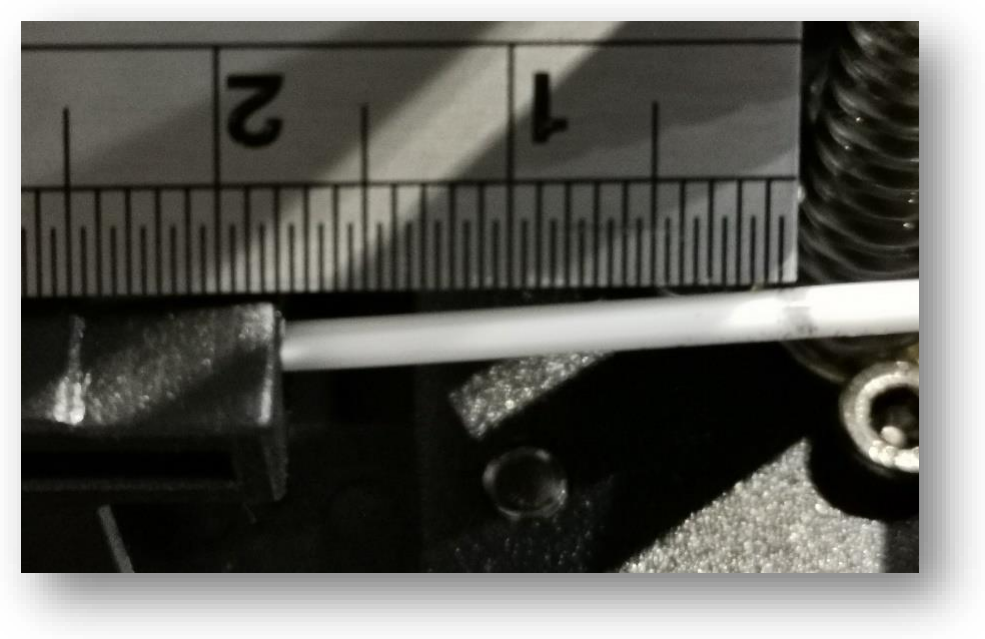
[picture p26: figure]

My measurement is 18mm, so my printer is under extruding!

### Step 6 Calculate the error

We wanted 20mm and got 18mm.

18mm / 20mm = 0.9
0.9 x 100 = 90%

So, my printer is under extruding by 10%

### Step 7 Calculate the new steps/mm value

So our current steps per unit value from step 2 is 405.

To calculate the new value simply divide by the answer above.

So, 405 / 0.9 = 450

Which makes sense as I need the stepper motor to do 10% more steps than it is right now.

If your printer is over extruding then the new number will be smaller.

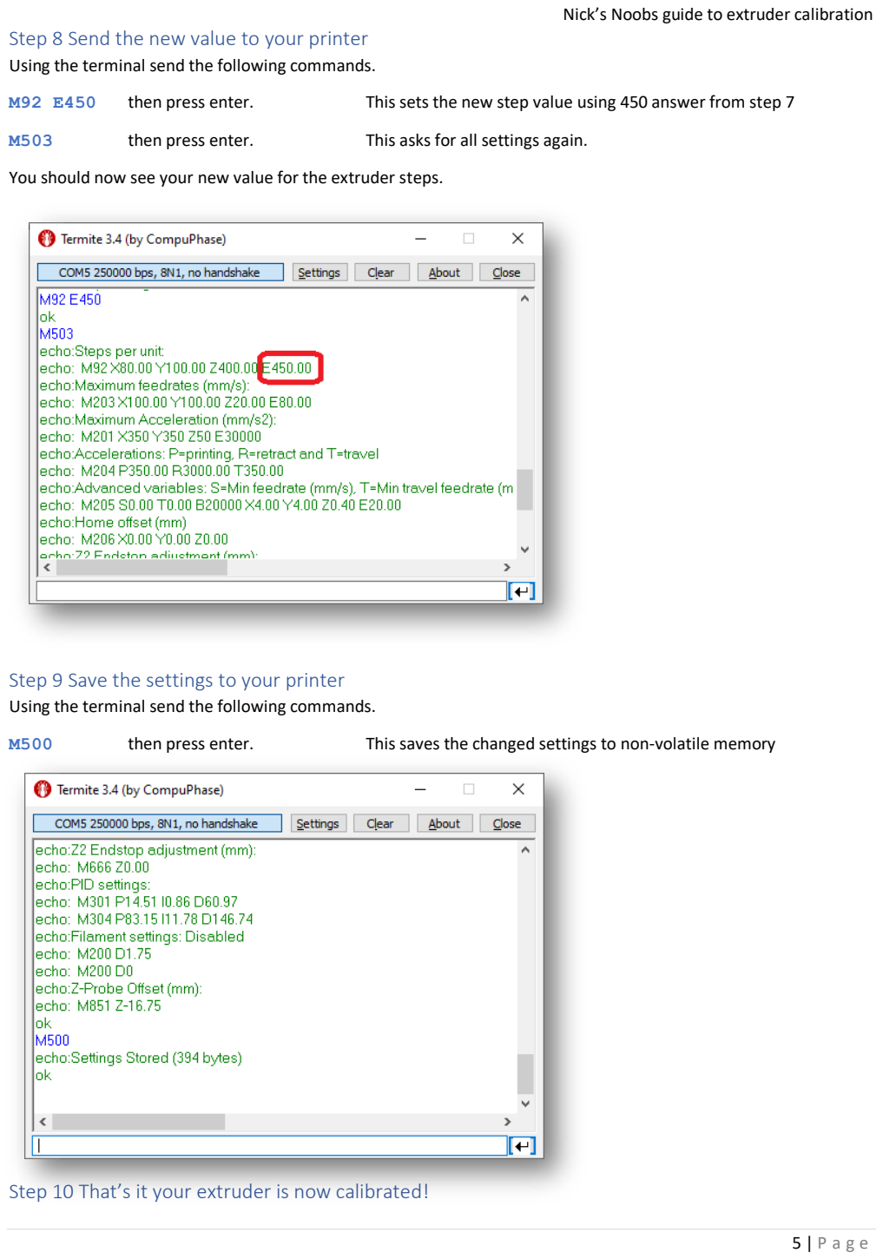
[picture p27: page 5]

### Step 8 Send the new value to your printer

Using the terminal send the following commands.

M92 E450 | then press enter. | This sets the new step value using 450 answer from step 7
M503 | then press enter. | This asks for all settings again.

You should now see your new value for the extruder steps.

### Step 9 Save the settings to your printer

Using the terminal send the following commands.

M500 | then press enter. | This saves the changed settings to non-volatile memory

### Step 10 That’s it your extruder is now calibrated!

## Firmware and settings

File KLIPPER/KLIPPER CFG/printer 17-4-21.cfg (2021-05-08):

[include kiauh_macros.cfg]
[include macro.cfg]

[mcu]
serial: /dev/serial/by-id/usb-Silicon_Labs_CP2102N_USB_to_UART_Bridge_Controller_1c951ae2dc4ee8118d3bc0eec2460985-if00-port0
pin_map: arduino
restart_method: arduino
#   This controls the mechanism the host will use to reset the
#   micro-controller. The choices are 'arduino', 'cheetah', 'rpi_usb',
#   and 'command'. The 'arduino' method (toggle DTR) is common on
#   Arduino boards and clones. The 'cheetah' method is a special
#   method needed for some Fysetc Cheetah boards. The 'rpi_usb' method
#   is useful on Raspberry Pi boards with micro-controllers powered
#   over USB - it briefly disables power to all USB ports to
#   accomplish a micro-controller reset. The 'command' method involves
#   sending a Klipper command to the micro-controller so that it can
#   reset itself. The default is 'arduino' if the micro-controller
#   communicates over a serial port, 'command' otherwise.

[output_pin power]
pin: ar15
value: 1
shutdown_value: 0

[display_status]

[virtual_sdcard]
path: ~/gcode_files
#required by FLUIDD do not comment

[respond]
default_type: echo
#   Sets the default prefix of the "M118" and "RESPOND" output to one
#   of the following:
#       echo: "echo: " (This is the default)
#       command: "// "
#       error: "!! "
#default_prefix: echo:
#   Directly sets the default prefix. If present, this value will
#   override the "default_type".

[idle_timeout]
gcode:
  M83
#set relative distance
  M109 S180 
#make sure that themp is ok for retracting
  G1 E-50 F600
#retract filament out of hot zone
  TURN_OFF_HEATERS
  M84
#disable motors
  M300 S440 P200
  M300 S660 P250
  M300 S880 P300
# play notification sound
  M118 NO COMMAND RECEIVED FOR 5 MIN. IDLE TIMEOUT
# WRITE IDLE NOTIFICATION ON CONSOLE
#   A list of G-Code commands to execute on an idle timeout. See
#   docs/Command_Templates.md for G-Code format. The default is to run
#   "TURN_OFF_HEATERS" and "M84".
timeout: 1800
#   Idle time (in seconds) to wait before running the above G-Code
#   commands. The default is 600 seconds.

[printer]
kinematics: cartesian
max_velocity: 200
#   Maximum velocity (in mm/s) of the toolhead (relative to the
#   print). This parameter must be specified.
max_accel: 500
#   Maximum acceleration (in mm/s^2) of the toolhead (relative to the
#   print). This parameter must be specified.

max_accel_to_decel: 250
#   A pseudo acceleration (in mm/s^2) controlling how fast the
#   toolhead may go from acceleration to deceleration. It is used to
#   reduce the top speed of short zig-zag moves (and thus reduce
#   printer vibration from these moves). The default is half of
#   max_accel.

square_corner_velocity: 5.0
#   The maximum velocity (in mm/s) that the toolhead may travel a 90
#   degree corner at. A non-zero value can reduce changes in extruder
#   flow rates by enabling instantaneous velocity changes of the
#   toolhead during cornering. This value configures the internal
#   centripetal velocity cornering algorithm; corners with angles
#   larger than 90 degrees will have a higher cornering velocity while
#   corners with angles less than 90 degrees will have a lower
#   cornering velocity. If this is set to zero then the toolhead will
#   decelerate to zero at each corner. The default is 5mm/s.
max_z_velocity: 5
max_z_accel: 30

[temperature_sensor Raspberry CPU]                             
sensor_type: temperature_host                                  
sensor_path: /sys/class/thermal/thermal_zone0/temp         

#[temperature_sensor TMC_2209]
#sensor_type: EPCOS 100K B57560G104F
#sensor_pin: analog15

#[temperature_sensor Power_supply]
#sensor_type: EPCOS 100K B57560G104F
#sensor_pin: analog12

[stepper_x]
step_pin: ar54
#dir_pin: !ar55
#SET THIS FOR A4988 stock driver
dir_pin: ar55
#SET THIS FOR TMC 2209 
enable_pin: !ar38
rotation_distance: 40
microsteps: 16
#step_distance: .0125
endstop_pin: ^!ar3
position_min: -5
position_endstop: -5
position_max: 400
homing_speed: 80.0

[tmc2209 stepper_x]
#uart_pin: ar11
#SET THIS FOR TMC 2209 without soldering SERVO PIN
#uart_pin: ar4
#SET THIS FOR TMC 2209 on SERVO PIN
uart_pin: ar51
#SET THIS FOR TMC 2209 on SPI pin to leave servo pwm free for rgb led
#microsteps:16
run_current: .95
hold_current: .4
stealthchop_threshold: 999

[stepper_y]
step_pin: ar60
#dir_pin: !ar61
#SET THIS FOR A4988 stock driver
dir_pin: ar61
#SET THIS FOR TMC 2209
enable_pin: !ar56
rotation_distance: 32
microsteps: 16
#step_distance: .01
endstop_pin: ^!ar42
position_endstop: 0
position_max: 400
homing_speed: 80.0

[tmc2209 stepper_y]
#uart_pin: ar15
#SET THIS FOR TMC 2209 without soldering SERVO PIN
#uart_pin: ar5
#SET THIS FOR TMC 2209 on SERVO PIN
uart_pin: ar52
#SET THIS FOR TMC 2209 on SPI pin to leave servo pwm free for rgb led
#microsteps:16
run_current: 1.2
hold_current: .4
stealthchop_threshold: 999

[stepper_z]
step_pin: ar46
#dir_pin: !ar48
#SET THIS FOR A4988 stock driver
dir_pin: ar48
#SET THIS FOR TMC 2209
enable_pin: !ar62
rotation_distance: 8
microsteps: 16
#step_distance: .0025
endstop_pin: ^ar18
position_endstop: 0.0
position_max: 450
position_min: -6.0
homing_speed: 5.0

[tmc2209 stepper_z]
#uart_pin: ar14
#microsteps:16
#SET THIS FOR TMC 2209 without soldering SERVO PIN
#uart_pin: ar6
#SET THIS FOR TMC 2209 on SERVO PIN
uart_pin: ar50
#SET THIS FOR TMC 2209 on SPI pin to leave servo pwm free for rgb led
run_current: .95
hold_current: .4
stealthchop_threshold: 1


[stepper_z1]
step_pin: ar36
dir_pin: !ar34
#SET THIS FOR A4988 stock driver
dir_pin: ar34
#SET THIS FOR TMC 2209
enable_pin: !ar30
rotation_distance: 8
microsteps: 16
#step_distance: .0025
endstop_pin: ^ar43

[tmc2209 stepper_z1]
#uart_pin: ar52
#SET THIS FOR TMC 2209 without soldering SERVO PIN
uart_pin: ar12
#SET THIS FOR TMC 2209 on SERVO PIN
#microsteps:16
run_current: .95
hold_current: .4
stealthchop_threshold: 1

[endstop_phase stepper_z]
#endstop_accuracy:
#   Sets the expected accuracy (in mm) of the endstop. This represents
#   the maximum error distance the endstop may trigger (eg, if an
#   endstop may occasionally trigger 100um early or up to 100um late
#   then set this to 0.200 for 200um). The default is
#   4*rotation_distance/full_steps_per_rotation.
#trigger_phase:
#   This specifies the phase of the stepper motor driver to expect
#   when hitting the endstop. It is composed of two numbers separated
#   by a forward slash character - the phase and the total number of
#   phases (eg, "7/64"). Only set this value if one is sure the
#   stepper motor driver is reset every time the mcu is reset. If this
#   is not set, then the stepper phase will be detected on the first
#   home and that phase will be used on all subsequent homes.
#endstop_align_zero: False
#   If true then the position_endstop of the axis will effectively be
#   modified so that the zero position for the axis occurs at a full
#   step on the stepper motor. (If used on the Z axis and the print
#   layer height is a multiple of a full step distance then every
#   layer will occur on a full step.) The default is False.

[safe_z_home]
home_xy_position: -5,0
#   A X,Y coordinate (e.g. 100,100) where the Z homing should be
#   performed. This parameter must be provided.
#speed: 50.0
#   Speed at which the toolhead is moved to the safe Z home
#   coordinate. The default is 50 mm/s
z_hop: 5
#   Distance (in mm) to lift the Z axis prior to homing. This is
#   applied to any homing command, even if it doesn't home the Z axis.
#   If the Z axis is already homed and the current Z position is less
#   than z_hop, then this will lift the head to a height of z_hop. If
#   the Z axis is not already homed, then prior to any XY homing
#   movement the Z axis boundary checks are disabled and the head is
#   lifted by z_hop. If z_hop is specified, be sure to home the Z
#   immediately after any XY home requests so that the Z boundary
#   checks are accurate. The default is to not implement Z hop.
#z_hop_speed: 20.0
#   Speed (in mm/s) at which the Z axis is lifted prior to homing. The
#   default is 20mm/s.
#move_to_previous: False
#   When set to True, xy are reset to their previous positions after z
#   homing. The default is False.
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

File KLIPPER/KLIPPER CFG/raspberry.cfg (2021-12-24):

[mcu host]
serial: /tmp/klipper_host_mcu

[gcode_button HOME]
pin: host:gpio2
#   The pin on which the button is connected. This parameter must be
#   provided.
#analog_range:
#   Two comma separated resistances (in Ohms) specifying the minimum
#   and maximum resistance range for the button. If analog_range is
#   provided then the pin must be an analog capable pin. The default
#   is to use digital gpio for the button.
#analog_pullup_resistor:
#   The pullup resistance (in Ohms) when analog_range is specified.
#   The default is 4700 ohms.
press_gcode:
    M300 S100 P20 ;quick beep to confirm button press (delete if you find it irritating)
    G28
#   A list of G-Code commands to execute when the button is pressed.
#   G-Code templates are supported. This parameter must be provided.
#release_gcode:
#   A list of G-Code commands to execute when the button is released.
#   G-Code templates are supported. The default is to not run any
#   commands on a button release.

[gcode_button pause]
pin: host:gpio4
press_gcode:
    M300 S100 P20 ;quick beep to confirm button press (delete if you find it irritating)
    PAUSE

[gcode_button resume]
pin: host:gpio3
press_gcode:
    M300 S100 P20 ;quick beep to confirm button press (delete if you find it irritating)
    RESUME

[gcode_button EMERGENCY]
pin: host:gpio17
press_gcode:
    M300 S100 P20 ;quick beep to confirm button press (delete if you find it irritating)
    M112
